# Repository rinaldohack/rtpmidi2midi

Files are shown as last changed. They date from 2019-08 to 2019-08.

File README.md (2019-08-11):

# rtpmidi2midi
rtpMIDI to MIDI converter based on ESP8266

basically, you need ESP8266 as boards for arduino, lathoub AppleMIDI library, and FortySeven MIDI Library. 
the eagle files are also available. This code was tested on Wemos D1 Mini and ESP-01. 

Note : not all functions were implemented. The one that were tested intensively are MIDI Note and MIDI CC.

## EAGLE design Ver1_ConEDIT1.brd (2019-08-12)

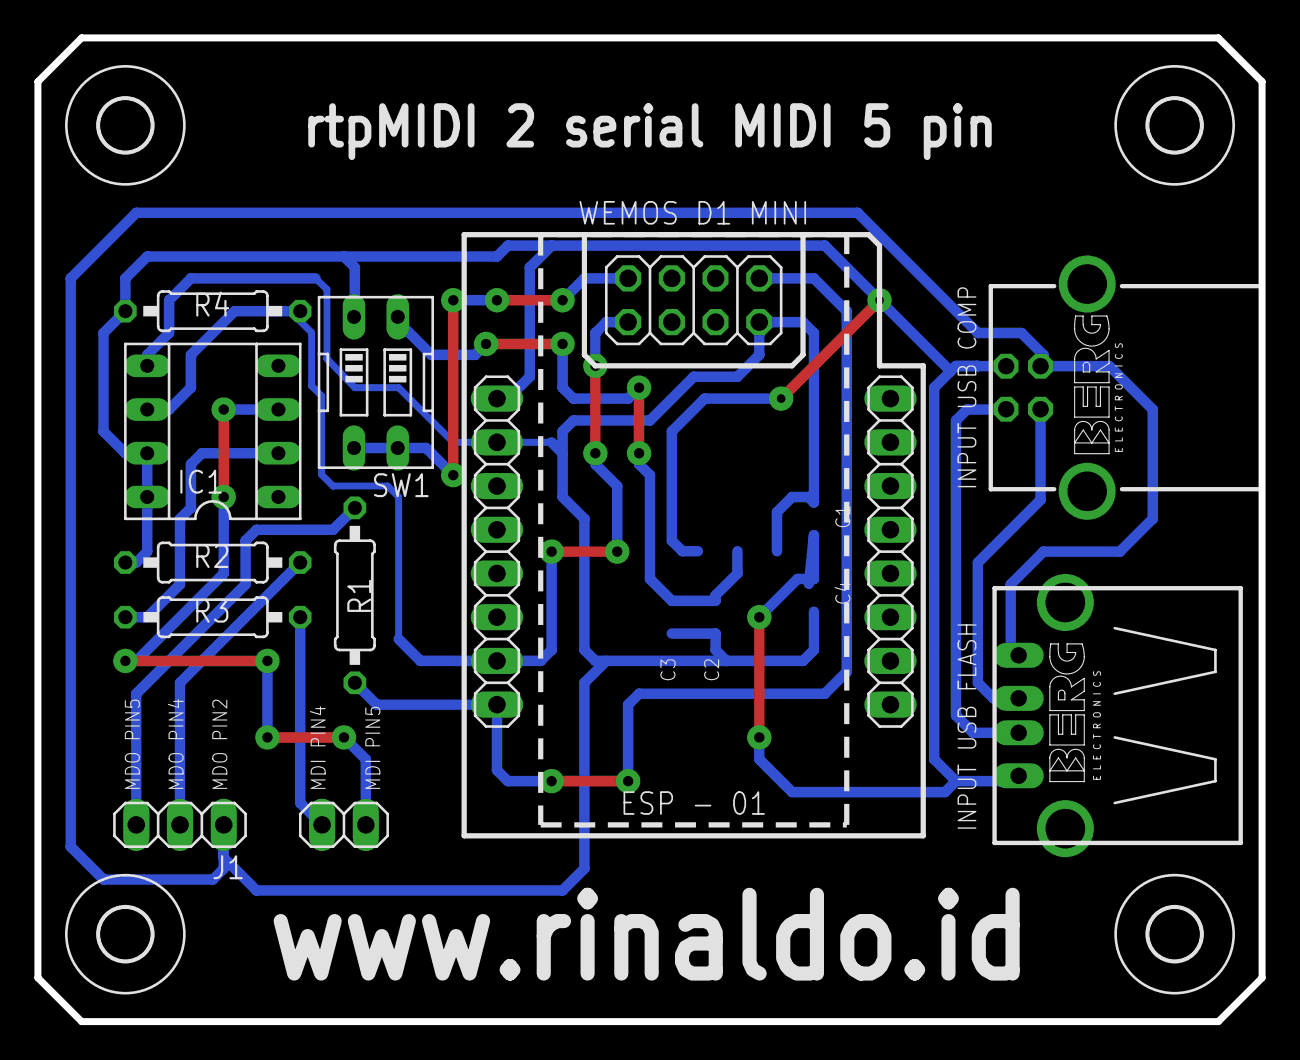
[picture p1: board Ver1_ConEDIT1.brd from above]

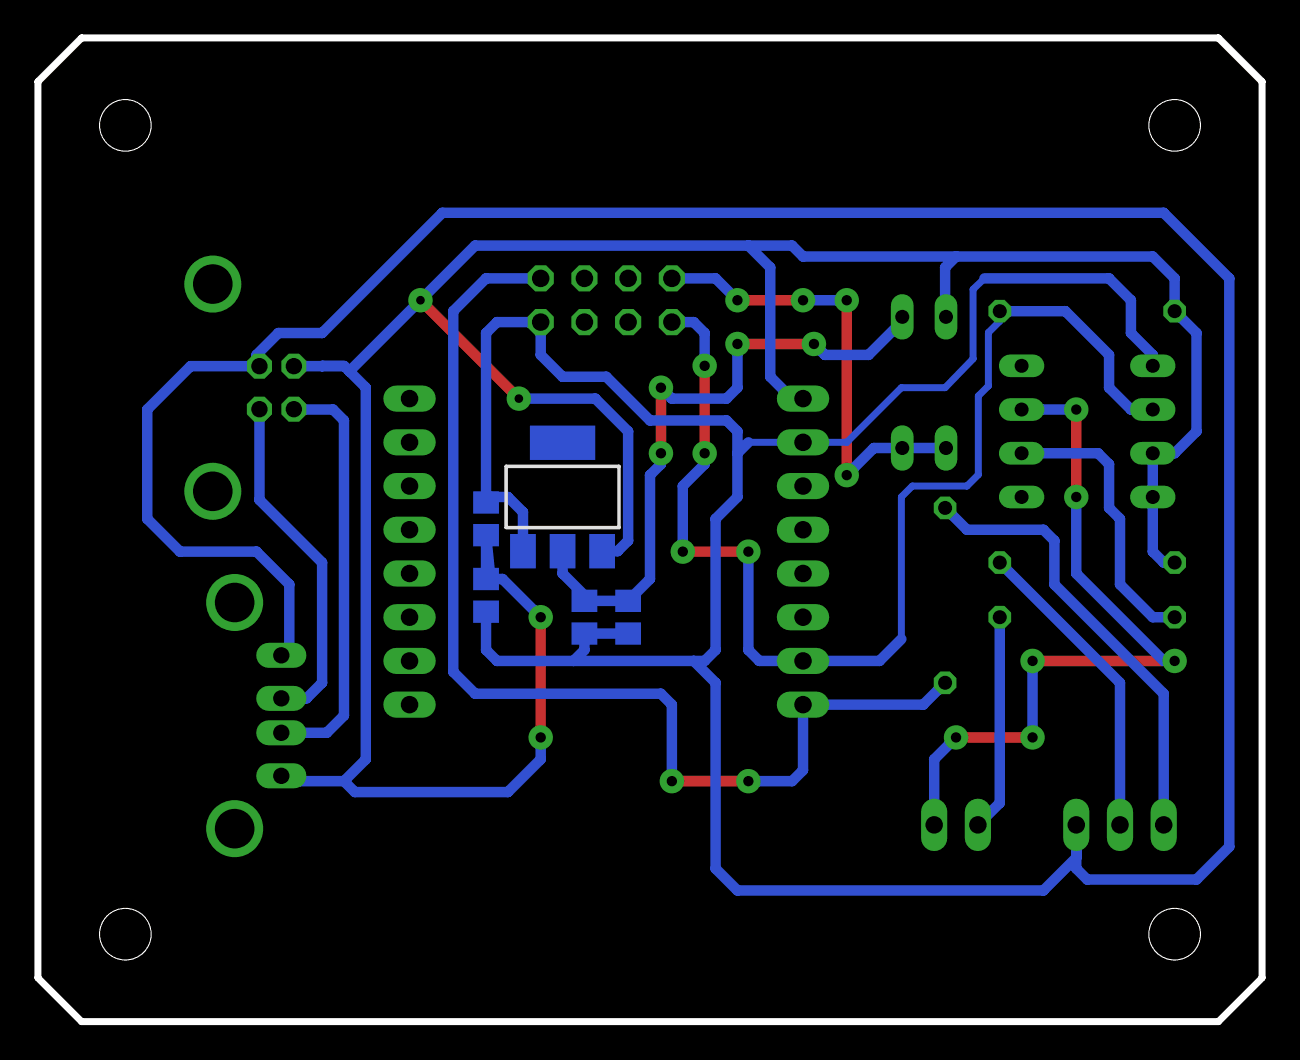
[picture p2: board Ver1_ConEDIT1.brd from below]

Board: 2 copper layers, 71.1 x 57.1 mm, 22 parts (5 on the bottom side), 13 nets.

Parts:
E$1: 2X04
E$2: 1X02
E$3: PN61729-S
E$4, E$7: 1X08
E$6: PN87520-S
E$11: SOT223
E$12, E$13, E$15, E$16: C0805
E$14, E$17, E$18, E$19: 3,0
IC1: SOCKET-08
J1: 1X03
R1, R2, R3, R4: 0207/10
SW1: EDG-02

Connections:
GND: E$3.4, E$6.4, E$11.1, E$12.2, E$13.2, E$15.2, E$16.1, IC1.5, J1.1
S$1: IC1.2, R3.1
S$2: E$11.2, E$12.1, E$15.1
S$3: IC1.6, R4.2
S$4: E$1.2, SW1.3, SW1.4
S$6: J1.3, R1.1
S$7: E$4.1, R1.2
S$8: J1.2, R2.1
S$10: E$3.2, E$6.2
S$11: E$3.3, E$6.3
S$12: E$2.2, IC1.3
S$13: E$2.1, R3.2
S$14: E$3.1, E$6.1, E$11.3, E$13.1, E$16.2, IC1.7, IC1.8, R2.2, R4.1

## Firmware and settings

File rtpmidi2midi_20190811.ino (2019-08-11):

// rtpMIDI to serial MIDI converter
// MIDI Thru is OFF
// created by Rinaldo Jonathan <https://rinaldo.id>
// built for Rinaldo's final project at Politeknik Caltex Riau <https://pcr.ac.id>, Diploma 3 Computer Engineer. 

// These need to be included when using standard Ethernet
#include <ESP8266WiFi.h>
#include <WiFiClient.h>
#include <WiFiUdp.h>

#include <AppleMidi.h>  // lathoub rtpMIDI llibrary <https://github.com/lathoub/Arduino-AppleMIDI-Library/>
#include <MIDI.h>       // FortySeven MIDI library  <https://github.com/FortySevenEffects/arduino_midi_library/>


char ssid[] = "systemv";   //  your network SSID (name)
char pass[] = "gakadapassword";             // your network password (use for WPA, or use as key for WEP)

unsigned long t0 = millis();
bool isConnected = false;

APPLEMIDI_CREATE_INSTANCE(WiFiUDP, AppleMIDI);  // start rtpMIDI
MIDI_CREATE_DEFAULT_INSTANCE();                 // start serial MIDI







// ====================================================================================
// Event handlers for incoming MIDI messages
// ====================================================================================

// -----------------------------------------------------------------------------
// rtpMIDI session. Device connected
// -----------------------------------------------------------------------------
void OnAppleMidiConnected(uint32_t ssrc, char* name) {
  isConnected  = true;
}

// -----------------------------------------------------------------------------
// rtpMIDI session. Device disconnected
// -----------------------------------------------------------------------------
void OnAppleMidiDisconnected(uint32_t ssrc) {
  isConnected  = false;
}

// -----------------------------------------------------------------------------
// rtpMIDI receive Note ON
// -----------------------------------------------------------------------------
void OnAppleMidiNoteOn(byte channel, byte note, byte velocity) {
  MIDI.sendNoteOn(note, velocity, channel); //send Note ON to serial MIDI
}

// -----------------------------------------------------------------------------
// rtpMIDI receive Note OFF
// -----------------------------------------------------------------------------
void OnAppleMidiNoteOff(byte channel, byte note, byte velocity) {
  MIDI.sendNoteOff(note, velocity, channel); //send Note Off to serial MIDI

}

// -----------------------------------------------------------------------------
// rtpMIDI receive MIDI CC
// -----------------------------------------------------------------------------
void OnAppleMidiCc(byte channel, byte number, byte value){
  MIDI.sendControlChange(number, value, channel); //send Note Off to serial MIDI

}


// rtpMIDI OnAppleMidiReceiveAfterTouchPoly
void OnAppleMidiReceiveAfterTouchPoly(byte channel, byte note, byte pressure)
{ 
  MIDI.sendAfterTouch(note,pressure,channel);
}

// rtpMIDI OnAppleMidiReceiveProgramChange
void OnAppleMidiReceiveProgramChange(byte channel, byte number)
{
  MIDI.sendProgramChange(number,channel);
}

// rtpMIDI OnAppleMidiReceiveAfterTouchChannel

void OnAppleMidiReceiveAfterTouchChannel(byte channel, byte pressure)
{
  MIDI.sendAfterTouch(pressure,channel);
}

// rtpMIDI OnAppleMidiReceivePitchBend
void OnAppleMidiReceivePitchBend(byte channel, int bend)
{
  MIDI.sendPitchBend(bend, channel);
}

// rtpMIDI OnAppleMidiReceiveTimeCodeQuarterFrame
void OnAppleMidiReceiveTimeCodeQuarterFrame(byte data)
{
  MIDI.sendTimeCodeQuarterFrame(data);
}



// -----------------------------------------------------------------------------
// serial MIDI receive Note ON
// -----------------------------------------------------------------------------
void OnSerialMidiNoteOn(byte channel, byte note, byte velocity)
{
  AppleMIDI.sendNoteOn(note, velocity, channel); //send Note On to rtpMIDI
}

// -----------------------------------------------------------------------------
// serial MIDI receive Note OFF
// -----------------------------------------------------------------------------
void OnSerialMidiNoteOff(byte channel, byte note, byte velocity)
{
  AppleMIDI.sendNoteOff(note, velocity, channel); //send Note OFF to rtpMIDI
}


// -----------------------------------------------------------------------------
// serial MIDI CC
// -----------------------------------------------------------------------------
void OnSerialMidiCC (byte channel, byte number, byte value)
{
  AppleMIDI.sendControlChange(number, value, channel); //send Note OFF to rtpMIDI
}



// OnSerialMidiAfterTouchPoly
void OnSerialMidiAfterTouchPoly(byte channel, byte note, byte pressure)
{
  AppleMIDI.sendPolyPressure(note, pressure, channel);
}

void OnSerialMidiProgramChange(byte channel, byte number)
{
  AppleMIDI.sendProgramChange(number,channel);
}

void OnSerialMidiAfterTouchChannel (byte channel, byte pressure)
{
  AppleMIDI.sendAfterTouch(pressure,channel); 
}

void OnSerialMidiPitchBend (byte channel, int bend)
{
  AppleMIDI.sendPitchBend(bend, channel);
}

void OnSerialMidiTimeCodeQuarterFrame (byte data)
{
  AppleMIDI.sendTimeCodeQuarterFrame(data); 
}
// -----------------------------------------------------------------------------
//
// -----------------------------------------------------------------------------
void setup()
{
  // Serial communications and wait for port to open:
  Serial.begin(115200);

  Serial.print(F("Getting IP address..."));

  
  WiFi.mode(WIFI_STA);
  WiFi.begin(ssid, pass);

  while (WiFi.status() != WL_CONNECTED) {
    delay(500);
    Serial.print(F("."));
  }
  
  Serial.println(F(""));
  Serial.println(F("WiFi connected"));
  Serial.print(WiFi.localIP());
  Serial.println(F(":5004")); 
  Serial.println();
   Serial.print("MAC: ");
   Serial.println(WiFi.macAddress());

  delay(5000);
  Serial.begin(31250);
  // Create a session and wait for a remote host to connect to us
  AppleMIDI.begin("test2");                            // rtpMIDI session name

  AppleMIDI.OnConnected(OnAppleMidiConnected);        // unused, leftover codes from examples
  AppleMIDI.OnDisconnected(OnAppleMidiDisconnected);  // unused, leftover codes from examples

  AppleMIDI.OnReceiveNoteOn(OnAppleMidiNoteOn);       // handle rtpMIDI Note ON
  AppleMIDI.OnReceiveNoteOff(OnAppleMidiNoteOff);     // handle rtpMIDI Note OFF
  AppleMIDI.OnReceiveControlChange(OnAppleMidiCc);    // handle rtpMIDI CC

  //handle everything else that I don't fully understand
  AppleMIDI.OnReceiveAfterTouchPoly(OnAppleMidiReceiveAfterTouchPoly);
  AppleMIDI.OnReceiveProgramChange(OnAppleMidiReceiveProgramChange);
  AppleMIDI.OnReceiveAfterTouchChannel(OnAppleMidiReceiveAfterTouchChannel);
  AppleMIDI.OnReceivePitchBend(OnAppleMidiReceivePitchBend);
  //AppleMIDI.OnReceiveSysEx(OnAppleMidiReceiveSysEx); //skipped
  AppleMIDI.OnReceiveTimeCodeQuarterFrame(OnAppleMidiReceiveTimeCodeQuarterFrame);
  //AppleMIDI.OnReceiveSongPosition(OnAppleMidiReceiveSongPosition);
  //AppleMIDI.OnReceiveSongSelect(OnAppleMidiReceiveSongSelect);
  //AppleMIDI.OnReceiveTuneRequest(OnAppleMidiReceiveTuneRequest);
  //AppleMIDI.OnReceiveClock(OnAppleMidiReceiveClock);
  //AppleMIDI.OnReceiveStart(OnAppleMidiReceiveStart);
  //AppleMIDI.OnReceiveContinue(OnAppleMidiReceiveContinue);
  //AppleMIDI.OnReceiveStop(OnAppleMidiReceiveStop);
  //AppleMIDI.OnReceiveActiveSensing(OnAppleMidiReceiveActiveSensing);
  //AppleMIDI.OnReceiveReset(OnAppleMidiReceiveReset);

  MIDI.begin(MIDI_CHANNEL_OMNI);                      // start serial MIDI
  MIDI.turnThruOff();                                 // because we don't need one

  MIDI.setHandleNoteOn(OnSerialMidiNoteOn);           // handle serial MIDI note ON, Put only the name of the function, 
  MIDI.setHandleNoteOff(OnSerialMidiNoteOff);         // handle serial MIDI note OFF
  MIDI.setHandleControlChange(OnSerialMidiCC);        // handle serial MIDI CC

  //handle everything else that I don't fully understand
  MIDI.setHandleAfterTouchPoly(OnSerialMidiAfterTouchPoly);
  MIDI.setHandleProgramChange(OnSerialMidiProgramChange);
  MIDI.setHandleAfterTouchChannel(OnSerialMidiAfterTouchChannel);
  MIDI.setHandlePitchBend(OnSerialMidiPitchBend);
  //MIDI.setHandleSystemExclusive(OnSerialMidiSysEx); //skipped
  MIDI.setHandleTimeCodeQuarterFrame(OnSerialMidiTimeCodeQuarterFrame);
  //MIDI.setHandleSongPosition(OnSerialMidiSongPosition); //skipped
  //MIDI.setHandleSongSelect(OnSerialMidiSongSelect); //skipped
  //MIDI.setHandleTuneRequest(OnSerialMidiTuneRequest); //skipped
  //MIDI.setHandleClock(OnSerialMidiClock); //skipped
  //MIDI.setHandleStart(OnSerialMidiStart); //skipped 
  //MIDI.setHandleContinue(OnSerialMidiContinue); //skipped
  //MIDI.setHandleStop(OnSerialMidiStop); //skipped
  //MIDI.setHandleActiveSensing(OnSerialMidiActiveSensing); /skipped
  //MIDI.setHandleSystemReset(OnSerialMidiReset); //skipped


}

// -----------------------------------------------------------------------------
//
// -----------------------------------------------------------------------------
void loop()
{
  // Listen to incoming notes
  AppleMIDI.read();
  MIDI.read();

}

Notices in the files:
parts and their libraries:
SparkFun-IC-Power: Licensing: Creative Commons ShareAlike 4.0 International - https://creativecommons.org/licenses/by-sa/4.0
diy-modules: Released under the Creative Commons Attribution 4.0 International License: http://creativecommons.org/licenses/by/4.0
